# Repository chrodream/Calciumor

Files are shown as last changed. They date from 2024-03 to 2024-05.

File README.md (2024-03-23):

# Calciumor
## 特徴
- ESP32-S3をベースとした電卓\/無線マクロパッド
- Li-Poバッテリーによる充電に対応
- 128×64ドットのOLED表示 or 128×32ドット + 7セグ表示器

## スペック
| 項目 | Min. | Typ. | Max. | 
| :--- | ---- | ---- | ---- |
| USB入力電圧 [V] | 4.75 | 5.0 | 5.25 | 
| 消費電流 (電卓/バッテリー) [mA] | | | | 
| 消費電流(マクロパッド/バッテリー) [mA] | | | |
| 消費電流 (電卓/USB) [mA] | | | 750 |
| 消費電流(マクロパッド/USB) [mA] | | | 750 |
| 消費電流(スリープ) [mA] | | | | 
| バッテリー容量 [mAh] | 400 | - | - | 
| バッテリー電圧範囲 [V] | 2.9 | - | 4.2 |

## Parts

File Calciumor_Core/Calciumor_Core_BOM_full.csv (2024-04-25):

Reference | Value | Datasheet | Footprint | Qty | DNP | LCSC
C17 | 1000p | ~ | Capacitor_SMD:C_0402_1005Metric | 1 |  | C1523
C2,C12 | 0.01u | ~ | Capacitor_SMD:C_0402_1005Metric | 2 |  | C15195
C1,C3,C4,C6,C15,C18,C21 | 0.1u | ~ | Capacitor_SMD:C_0402_1005Metric | 7 |  | C307331
C10 | 1u | ~ | Capacitor_SMD:C_0402_1005Metric | 1 |  | C52923
C9,C11 | 4.7u | ~ | Capacitor_SMD:C_0603_1608Metric | 2 |  | C19666
C5,C7,C8 | 10u | ~ | Capacitor_SMD:C_0805_2012Metric | 3 |  | C440198
R27,R28 | 33 | ~ | Resistor_SMD:R_0603_1608Metric | 2 |  | C23140
R26 | 100 | ~ | Resistor_SMD:R_0603_1608Metric | 1 |  | C22775
R14 | 330 | ~ | Resistor_SMD:R_0402_1005Metric | 1 |  | C25104
R22,R33 | 470 | ~ | Resistor_SMD:R_0402_1005Metric | 2 |  | C25117
R11,R12,R13,R15 | 1k | ~ | Resistor_SMD:R_0402_1005Metric | 4 |  | C11702
R18 | 3.9k | ~ | Resistor_SMD:R_1206_3216Metric | 1 | DNP
R16,R17 | 5.1k | ~ | Resistor_SMD:R_0402_1005Metric | 2 |  | C25905
R8,R9,R10,R19,R23,R24,R25,R31 | 10k | ~ | Resistor_SMD:R_0402_1005Metric | 8 |  | C25744
R20 | 13k | ~ | Resistor_SMD:R_0603_1608Metric | 1 |  | C22797
R1 | 33k | ~ | Resistor_SMD:R_0603_1608Metric | 1 |  | C22967
R21 | 33k | ~ | Resistor_SMD:R_0402_1005Metric | 1 |  | C25779
R3,R4,R5,R29 | 100k | ~ | Resistor_SMD:R_0402_1005Metric | 4 |  | C25741
R2,R30 | 330k | ~ | Resistor_SMD:R_0603_1608Metric | 2 |  | C23137
R6 | 470k | ~ | Resistor_SMD:R_0603_1608Metric | 1 |  | C23178
R7 | 1M | ~ | Resistor_SMD:R_0603_1608Metric | 1 |  | C22935
U10 | AE-XC9306-5V |  | Calciumor:AE-XC9306-3V3 | 1 | DNP
U9 | AE-XC9306-3V3 |  | Calciumor:AE-XC9306-3V3 | 1 | DNP
D21 | B.Stat LED1 (White) | ~ | LED_SMD:LED_0603_1608Metric | 1 | DNP
D20 | B.Stat LED2 (White) | ~ | LED_SMD:LED_0603_1608Metric | 1 | DNP
D11 | B.Stat LED3 (White) | ~ | LED_SMD:LED_0603_1608Metric | 1 | DNP
D10 | B.Stat LED4 (White) | ~ | LED_SMD:LED_0603_1608Metric | 1 | DNP
U5 | BD5229G-1 |  | Package_TO_SOT_SMD:SOT-23-5 | 1 | DNP
J6 | Conn_01x05_Pin | ~ | Connector_JST:JST_PH_S4B-PH-SM4-TB_1x04-1MP_P2.00mm_Horizontal | 1 | DNP
J1 | Conn_01x07_Pin | ~ | Connector_JST:JST_PH_S6B-PH-SM4-TB_1x06-1MP_P2.00mm_Horizontal | 1 | DNP
D1,D2,D3,D4,D5,D6,D7,D8,D9,D12,D13,D14,D15,D16,D17,D18,D19 | D | ~ | Diode_SMD:D_SOD-123 | 17 |  | C81598
D23,D25 | DF3D18FU,LF | ~ | Package_TO_SOT_SMD:SOT-323_SC-70 | 2 | DNP
U3 | ESP32-S3-WROOM-1-N16R8 | https://www.espressif.com/sites/default/files/documentation/esp32-s3-wroom-1_wroom-1u_datasheet_en.pdf | RF_Module:ESP32-S3-WROOM-1 | 1 | DNP
D27 | LED Charging(Yellow) | ~ | LED_SMD:LED_0603_1608Metric | 1 | DNP
D24 | LED Power(White) | ~ | LED_SMD:LED_0603_1608Metric | 1 | DNP
J5 | Li-Po(PH_S2B_SMD) | ~ | Connector_JST:JST_PH_S2B-PH-SM4-TB_1x02-1MP_P2.00mm_Horizontal | 1
U1 | LM324APT |  | Package_SO:TSSOP-14_4.4x5mm_P0.65mm | 1 |  | C111180
U4 | MCP73831-2-OT | http://ww1.microchip.com/downloads/en/DeviceDoc/20001984g.pdf | Package_TO_SOT_SMD:SOT-23-5 | 1 | DNP
F1,F2 | MF-NSMF035X | ~ | Calciumor:MF-NSMF | 2 | DNP
H4,H7,H8,H10,H11 | MountingHole | ~ | MountingHole:MountingHole_2.2mm_M2 | 5 | DNP
U7 | NC7SV157 |  | Package_TO_SOT_SMD:SOT-363_SC-70-6 | 1 |  | C184123
J4 | NeoPixel | ~ | Connector_JST:JST_PH_S4B-PH-SM4-TB_1x04-1MP_P2.00mm_Horizontal | 1 | DNP
U2 | NJM12877F25 |  | Package_TO_SOT_SMD:SOT-23-5 | 1 | DNP
SW20 | Power_SW | ~ | Calciumor:THBP07 | 1 | DNP
SW4 | RotaryEncoder_Switch | ~ | Ultramarine-2:EC12 | 1 | DNP
D26,D28 | SS2040FL | ~ | Diode_SMD:D_SOD-123F | 2 | DNP
SW1,SW2,SW3,SW5,SW6,SW7,SW8,SW9,SW10,SW11,SW12,SW13,SW14,SW15,SW16,SW17,SW18 | SW_Push | ~ | Calciumor:MX_Choc_Socket | 17 | DNP
SW19 | TMHU27 |  | Calciumor:TMHU27 | 1 | DNP
SW21 | TVAF06 | ~ | Ultramarine-2:TVAF06 | 1
J2 | USB_C_Main | https://www.usb.org/sites/default/files/documents/usb_type-c.zip | Connector_USB:USB_C_Receptacle_G-Switch_GT-USB-7010ASV | 1 |  | C2988369
U8 | XC6194AA05ER-G |  | Calciumor:XC6194 | 1 |  | C18221112

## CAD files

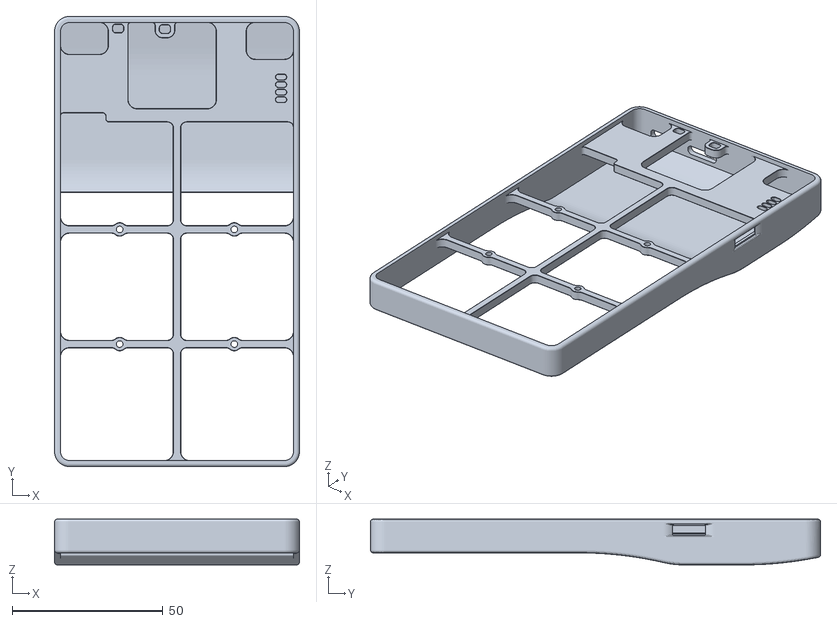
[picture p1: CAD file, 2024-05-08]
Calciumor_3DModel/Shell.stl
81.2 x 149.2 x 15.2

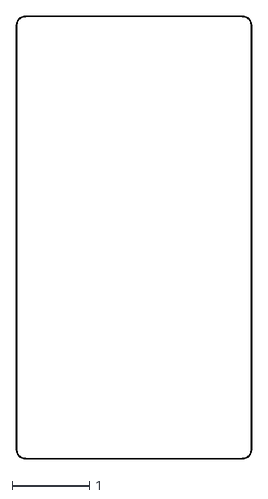
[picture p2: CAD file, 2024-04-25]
Calciumor_Core/Calciumor_Core-Edge_Cuts.dxf
3.04 x 5.71

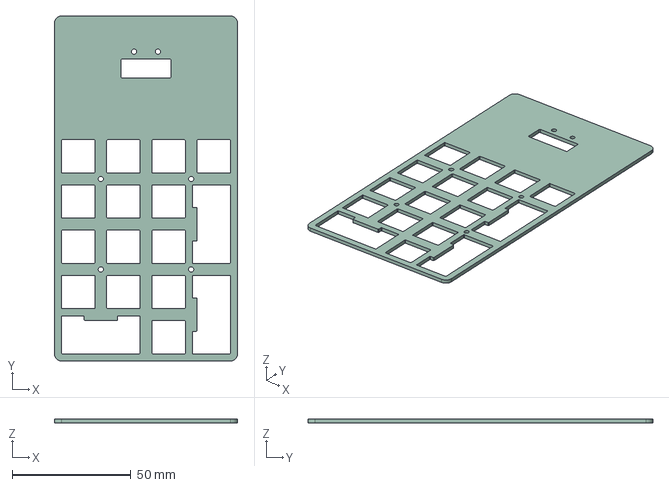
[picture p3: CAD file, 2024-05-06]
Calciumor_SwitchCover/Calciumor_SwitchCover.step
77.0 x 145.0 x 1.60 mm

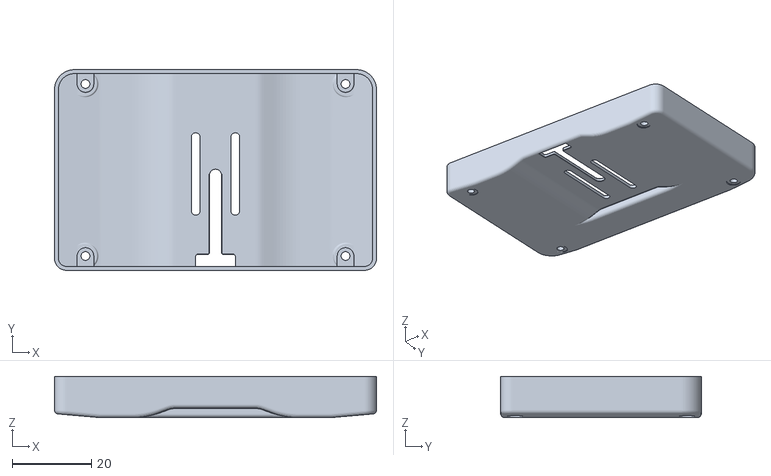
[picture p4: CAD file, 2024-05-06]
Calciumor_3DModel/OLED_Base.stl
81.2 x 50.6 x 10.4

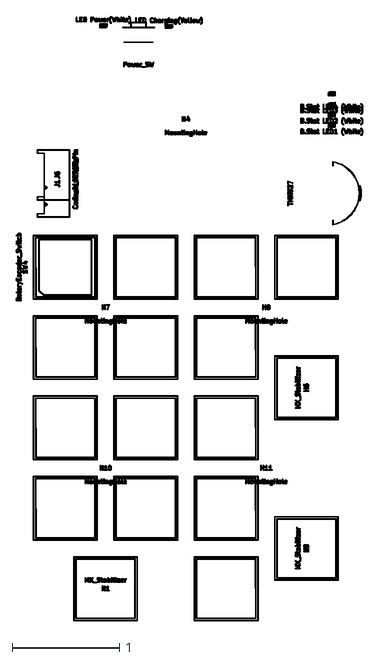
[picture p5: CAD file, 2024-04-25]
Calciumor_Core/Calciumor_Core-F_Fab.dxf
3.23 x 5.62

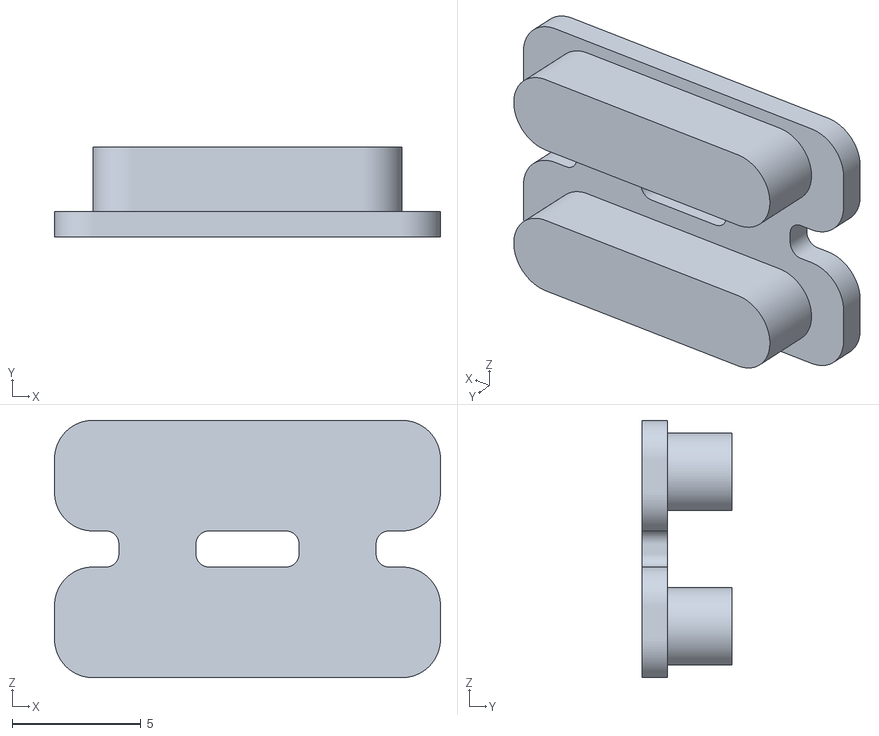
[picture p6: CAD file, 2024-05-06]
Calciumor_3DModel/Pow_SW.stl
15.0 x 3.50 x 10.00

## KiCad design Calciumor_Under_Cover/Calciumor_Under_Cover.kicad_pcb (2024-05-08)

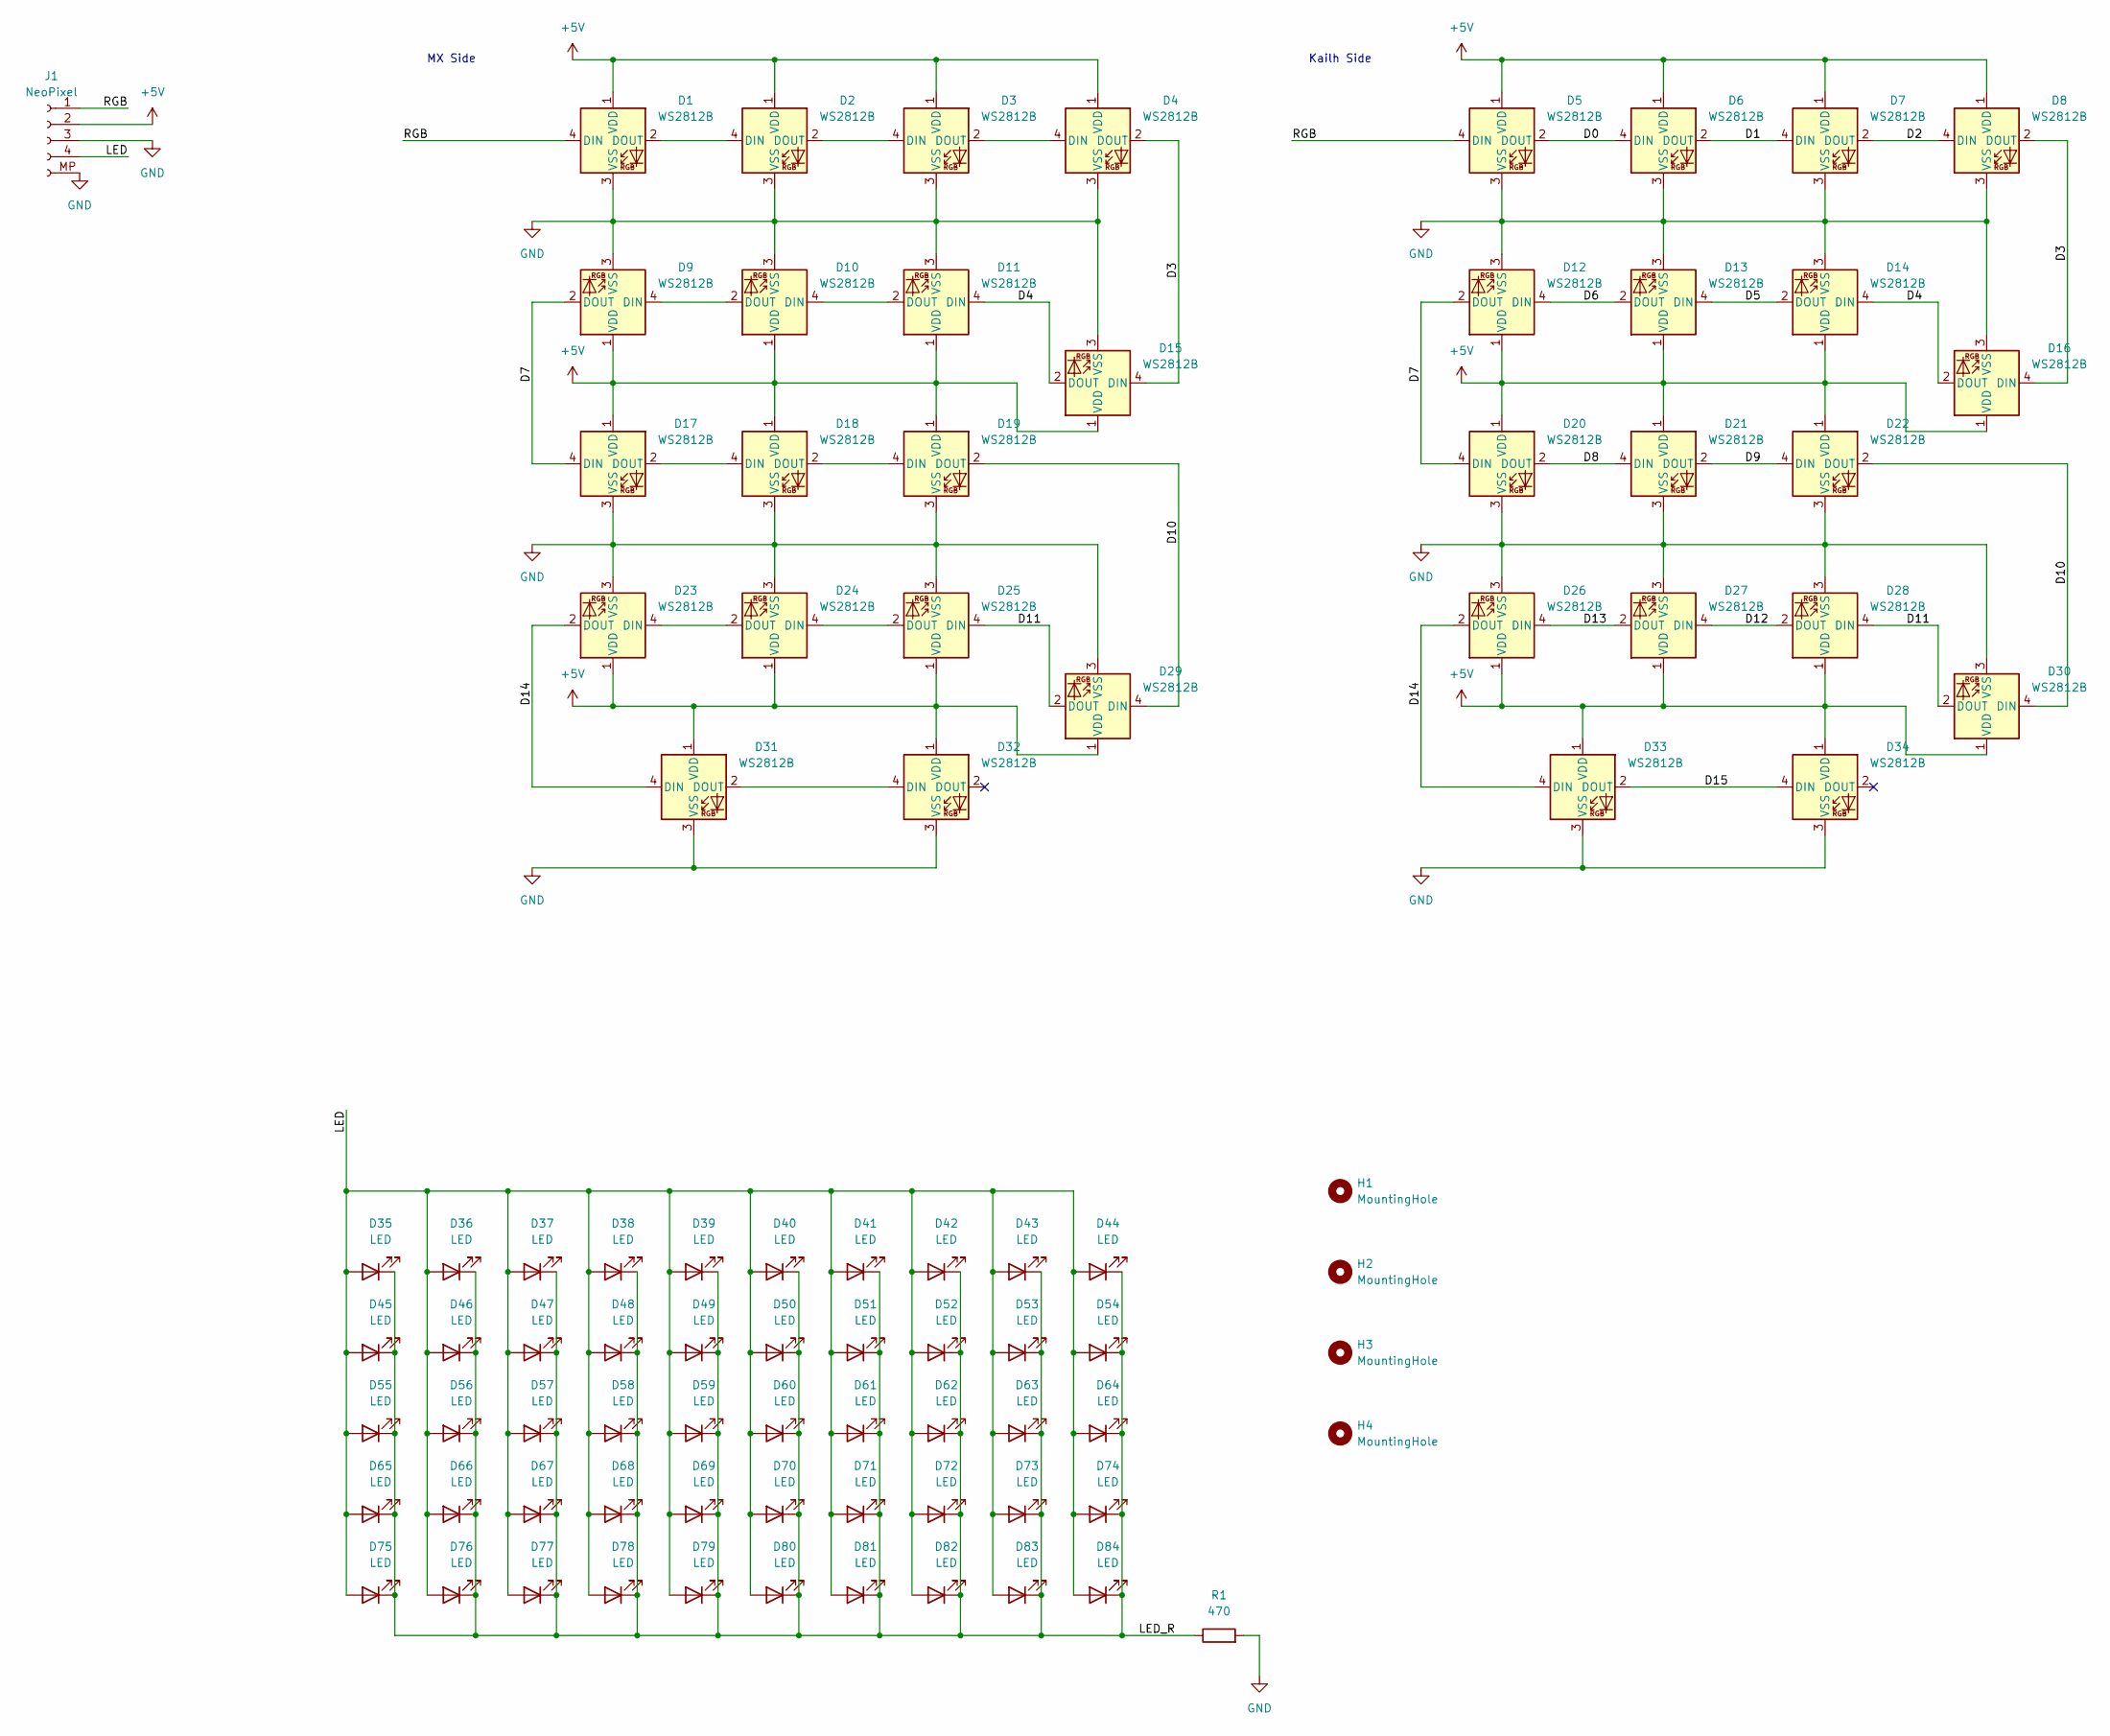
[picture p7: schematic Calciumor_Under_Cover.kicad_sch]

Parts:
D1, D2, D3, D4, D5, D6, D7, D8, D9, D10, D11, D12, D13, D14, D15, D16, D17, D18, D19, D20, D21, D22, D23, D24, D25, D26, D27, D28, D29, D30, D31, D32, D33, D34: WS2812B; LED_WS2812B_PLCC4_5.0x5.0mm_P3.2mm; LCSC C2843785
D35, D36, D37, D38, D39, D40, D41, D42, D43, D44, D45, D46, D47, D48, D49, D50, D51, D52, D53, D54, D55, D56, D57, D58, D59, D60, D61, D62, D63, D64, D65, D66, D67, D68, D69, D70, D71, D72, D73, D74, D75, D76, D77, D78, D79, D80, D81, D82, D83, D84: LED; LED_0603_1608Metric; LCSC C2290
H1, H2, H3, H4: MountingHole; MountingHole_2.2mm_M2
J1: NeoPixel; JST_PH_S4B-PH-SM4-TB_1x04-1MP_P2.00mm_Horizontal
R1: 470; R_1206_3216Metric

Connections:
+5V: D1.1 (VDD), D2.1 (VDD), D3.1 (VDD), D4.1 (VDD), D5.1 (VDD), D6.1 (VDD), D7.1 (VDD), D8.1 (VDD), D9.1 (VDD), D10.1 (VDD), D11.1 (VDD), D12.1 (VDD), D13.1 (VDD), D14.1 (VDD), D15.1 (VDD), D16.1 (VDD), D17.1 (VDD), D18.1 (VDD), D19.1 (VDD), D20.1 (VDD), D21.1 (VDD), D22.1 (VDD), D23.1 (VDD), D24.1 (VDD), D25.1 (VDD), D26.1 (VDD), D27.1 (VDD), D28.1 (VDD), D29.1 (VDD), D30.1 (VDD), D31.1 (VDD), D32.1 (VDD), D33.1 (VDD), D34.1 (VDD), J1.2
/D0: D5.2 (DOUT), D6.4 (DIN)
/D1: D6.2 (DOUT), D7.4 (DIN)
/D2: D7.2 (DOUT), D8.4 (DIN)
/D3: D4.2 (DOUT), D8.2 (DOUT), D15.4 (DIN), D16.4 (DIN)
/D4: D11.4 (DIN), D14.4 (DIN), D15.2 (DOUT), D16.2 (DOUT)
/D5: D13.4 (DIN), D14.2 (DOUT)
/D6: D12.4 (DIN), D13.2 (DOUT)
/D7: D9.2 (DOUT), D12.2 (DOUT), D17.4 (DIN), D20.4 (DIN)
/D8: D20.2 (DOUT), D21.4 (DIN)
/D9: D21.2 (DOUT), D22.4 (DIN)
/D10: D19.2 (DOUT), D22.2 (DOUT), D29.4 (DIN), D30.4 (DIN)
/D11: D25.4 (DIN), D28.4 (DIN), D29.2 (DOUT), D30.2 (DOUT)
/D12: D27.4 (DIN), D28.2 (DOUT)
/D13: D26.4 (DIN), D27.2 (DOUT)
/D14: D23.2 (DOUT), D26.2 (DOUT), D31.4 (DIN), D33.4 (DIN)
/D15: D33.2 (DOUT), D34.4 (DIN)
/LED: D35.2 (A), D36.2 (A), D37.2 (A), D38.2 (A), D39.2 (A), D40.2 (A), D41.2 (A), D42.2 (A), D43.2 (A), D44.2 (A), D45.2 (A), D46.2 (A), D47.2 (A), D48.2 (A), D49.2 (A), D50.2 (A), D51.2 (A), D52.2 (A), D53.2 (A), D54.2 (A), D55.2 (A), D56.2 (A), D57.2 (A), D58.2 (A), D59.2 (A), D60.2 (A), D61.2 (A), D62.2 (A), D63.2 (A), D64.2 (A), D65.2 (A), D66.2 (A), D67.2 (A), D68.2 (A), D69.2 (A), D70.2 (A), D71.2 (A), D72.2 (A), D73.2 (A), D74.2 (A), D75.2 (A), D76.2 (A), D77.2 (A), D78.2 (A), D79.2 (A), D80.2 (A), D81.2 (A), D82.2 (A), D83.2 (A), D84.2 (A), J1.4
/LED_R: D35.1 (K), D36.1 (K), D37.1 (K), D38.1 (K), D39.1 (K), D40.1 (K), D41.1 (K), D42.1 (K), D43.1 (K), D44.1 (K), D45.1 (K), D46.1 (K), D47.1 (K), D48.1 (K), D49.1 (K), D50.1 (K), D51.1 (K), D52.1 (K), D53.1 (K), D54.1 (K), D55.1 (K), D56.1 (K), D57.1 (K), D58.1 (K), D59.1 (K), D60.1 (K), D61.1 (K), D62.1 (K), D63.1 (K), D64.1 (K), D65.1 (K), D66.1 (K), D67.1 (K), D68.1 (K), D69.1 (K), D70.1 (K), D71.1 (K), D72.1 (K), D73.1 (K), D74.1 (K), D75.1 (K), D76.1 (K), D77.1 (K), D78.1 (K), D79.1 (K), D80.1 (K), D81.1 (K), D82.1 (K), D83.1 (K), D84.1 (K), R1.1
/RGB: D1.4 (DIN), D5.4 (DIN), J1.1
GND: D1.3 (VSS), D2.3 (VSS), D3.3 (VSS), D4.3 (VSS), D5.3 (VSS), D6.3 (VSS), D7.3 (VSS), D8.3 (VSS), D9.3 (VSS), D10.3 (VSS), D11.3 (VSS), D12.3 (VSS), D13.3 (VSS), D14.3 (VSS), D15.3 (VSS), D16.3 (VSS), D17.3 (VSS), D18.3 (VSS), D19.3 (VSS), D20.3 (VSS), D21.3 (VSS), D22.3 (VSS), D23.3 (VSS), D24.3 (VSS), D25.3 (VSS), D26.3 (VSS), D27.3 (VSS), D28.3 (VSS), D29.3 (VSS), D30.3 (VSS), D31.3 (VSS), D32.3 (VSS), D33.3 (VSS), D34.3 (VSS), J1.3, J1.MP (Pin_5), R1.2
unnamed: D1.2 (DOUT), D2.4 (DIN)
unnamed: D2.2 (DOUT), D3.4 (DIN)
unnamed: D3.2 (DOUT), D4.4 (DIN)
unnamed: D10.4 (DIN), D11.2 (DOUT)
unnamed: D9.4 (DIN), D10.2 (DOUT)
unnamed: D17.2 (DOUT), D18.4 (DIN)
unnamed: D18.2 (DOUT), D19.4 (DIN)
unnamed: D23.4 (DIN), D24.2 (DOUT)
unnamed: D24.4 (DIN), D25.2 (DOUT)
unnamed: D31.2 (DOUT), D32.4 (DIN)

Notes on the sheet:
Kailh Side
MX Side

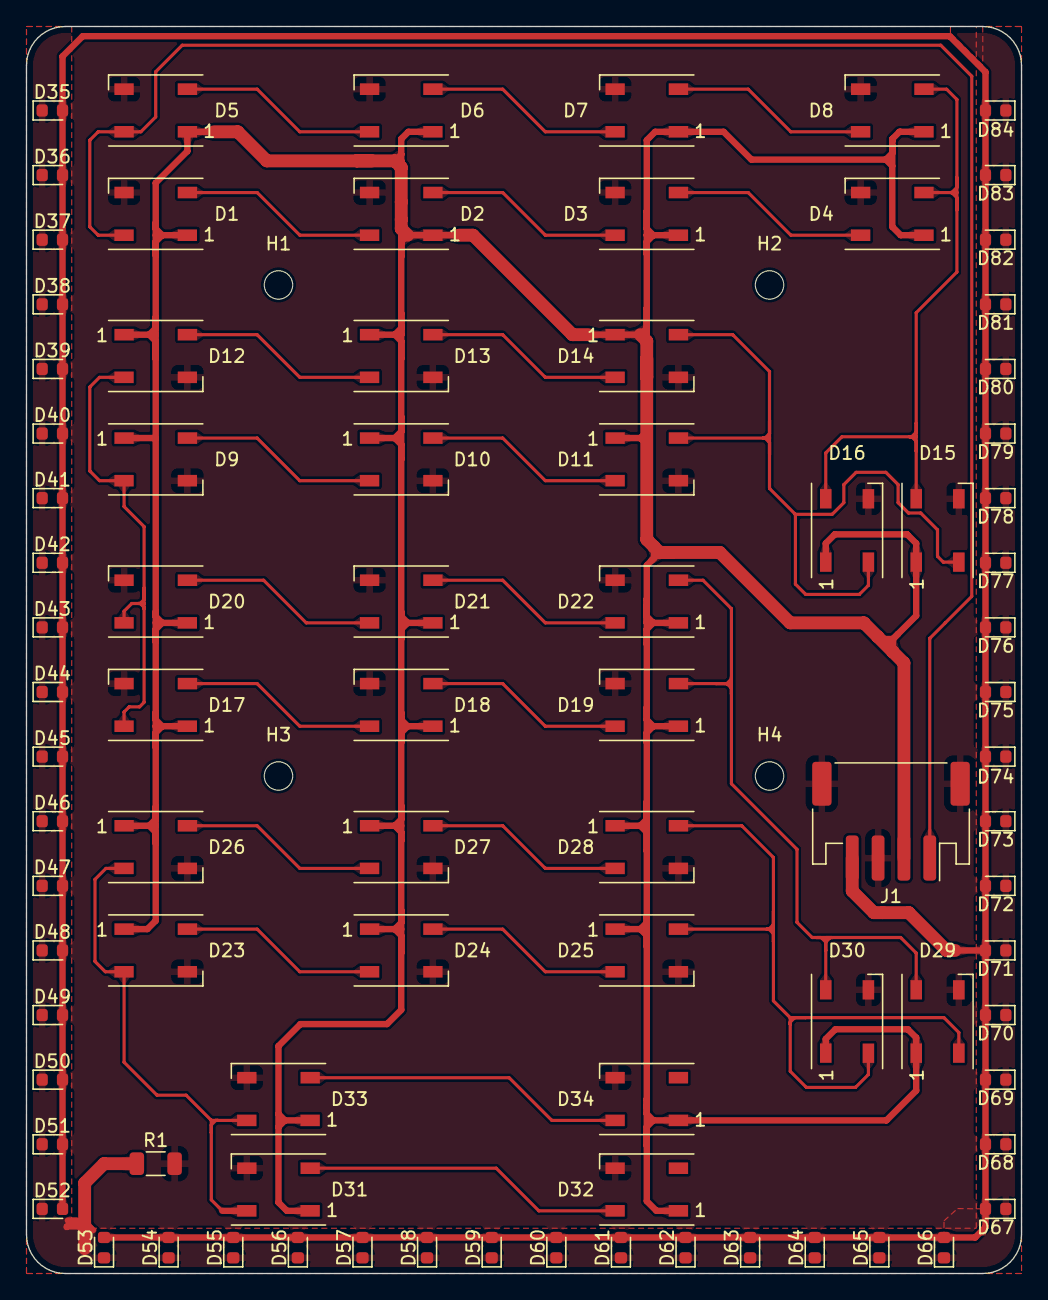
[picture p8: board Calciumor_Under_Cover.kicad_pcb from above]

Board: 2 copper layers, 77.0 x 96.5 mm, 90 parts (0 on the bottom side), 31 nets.

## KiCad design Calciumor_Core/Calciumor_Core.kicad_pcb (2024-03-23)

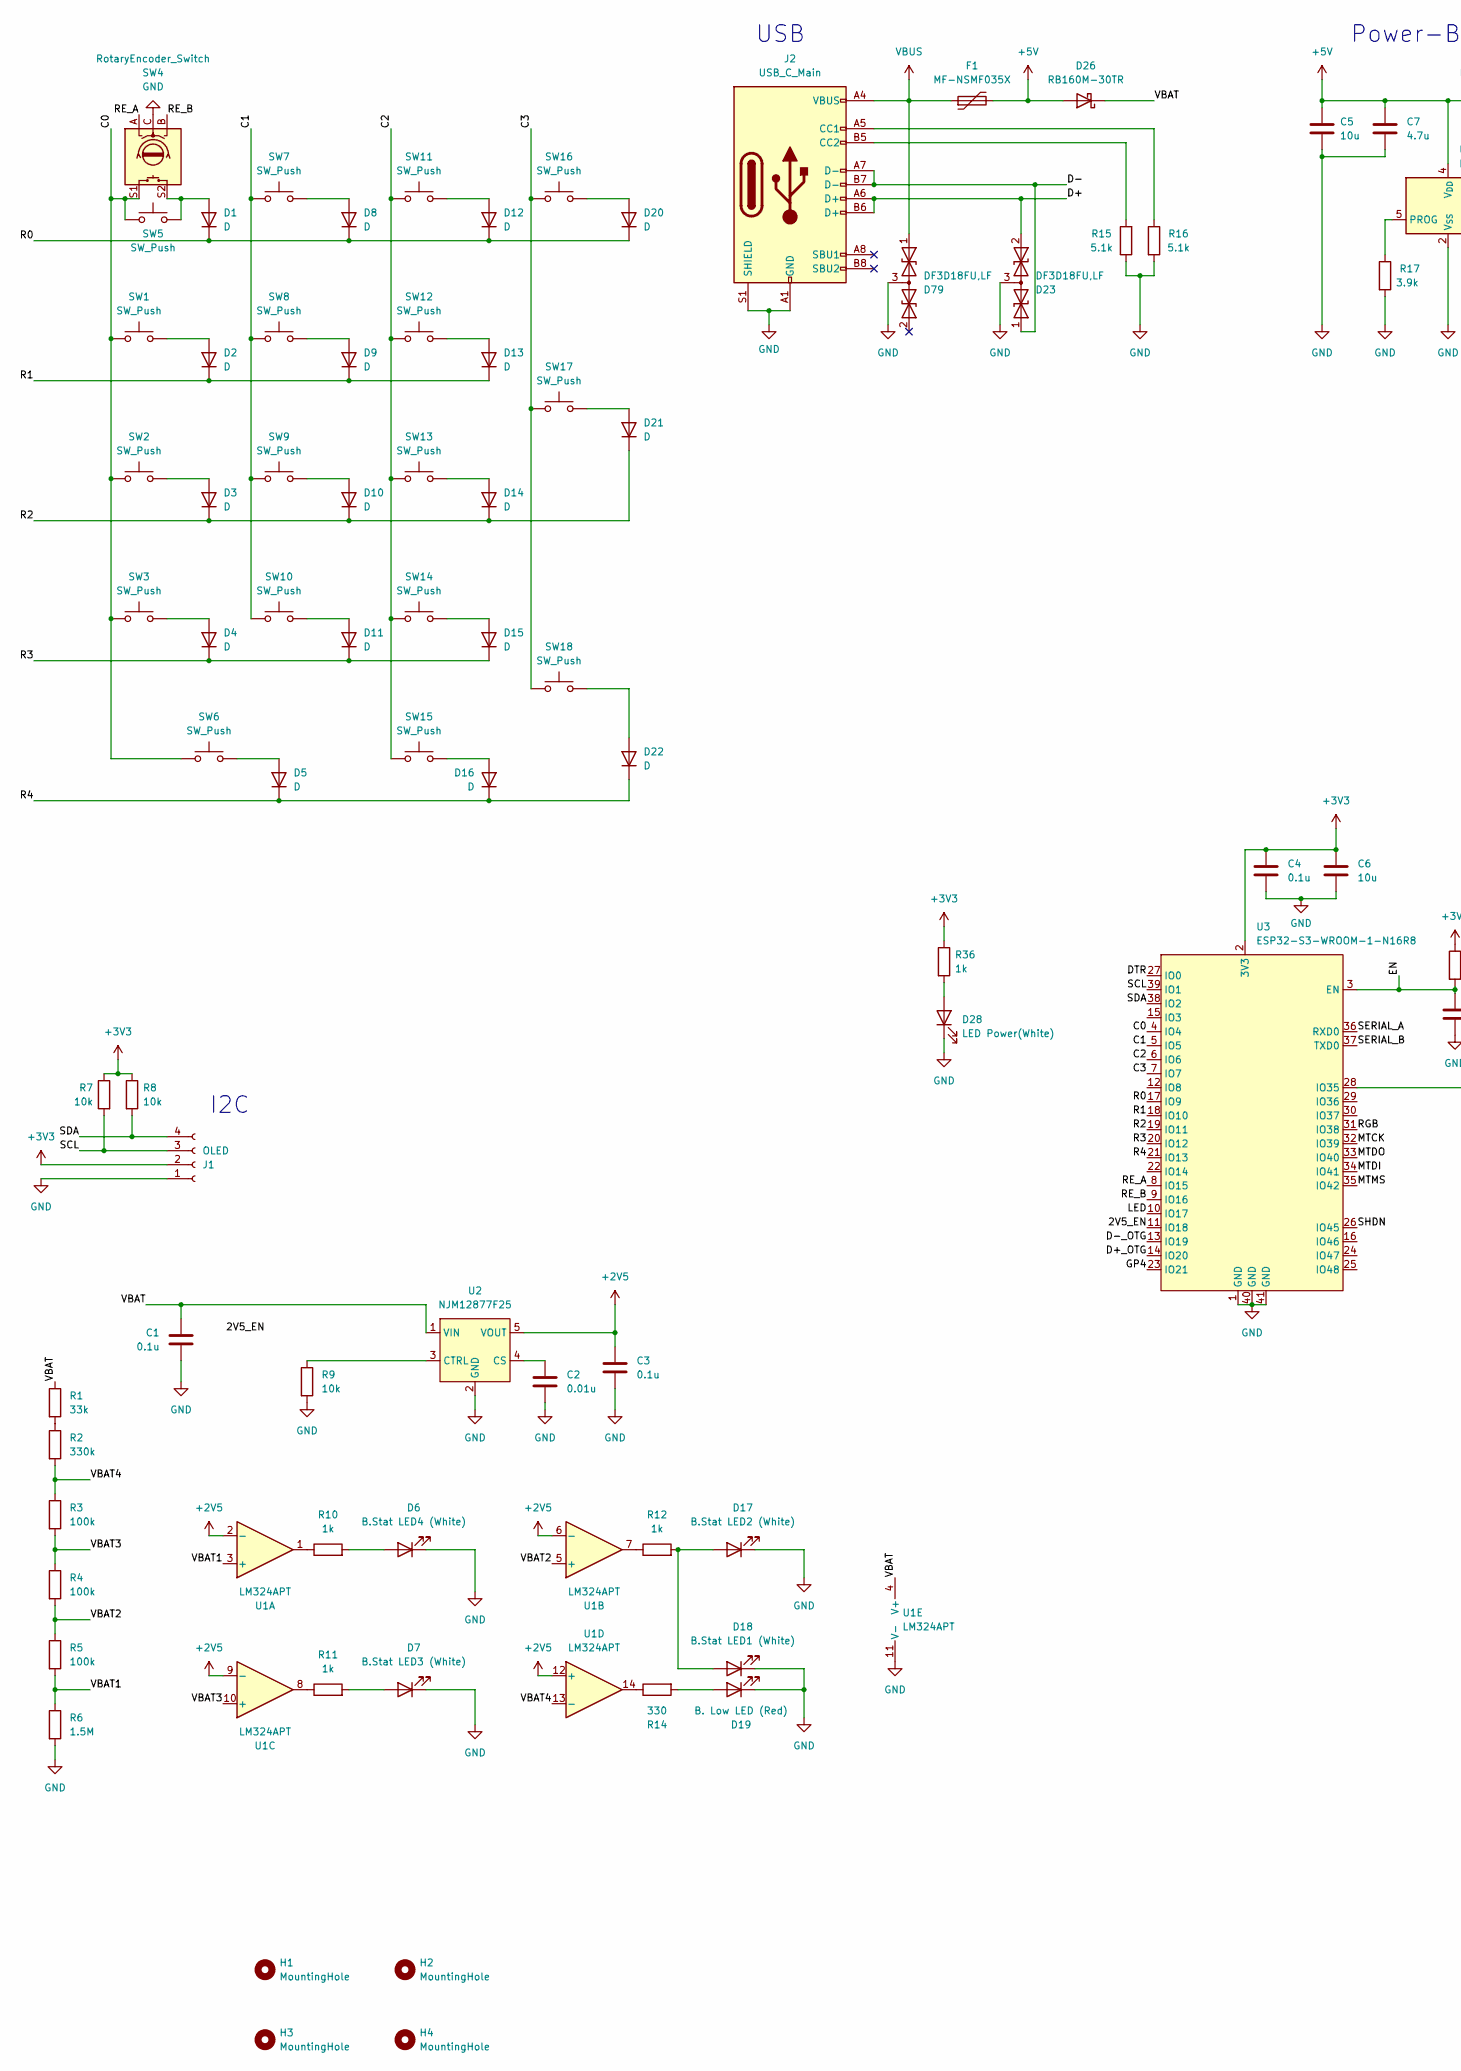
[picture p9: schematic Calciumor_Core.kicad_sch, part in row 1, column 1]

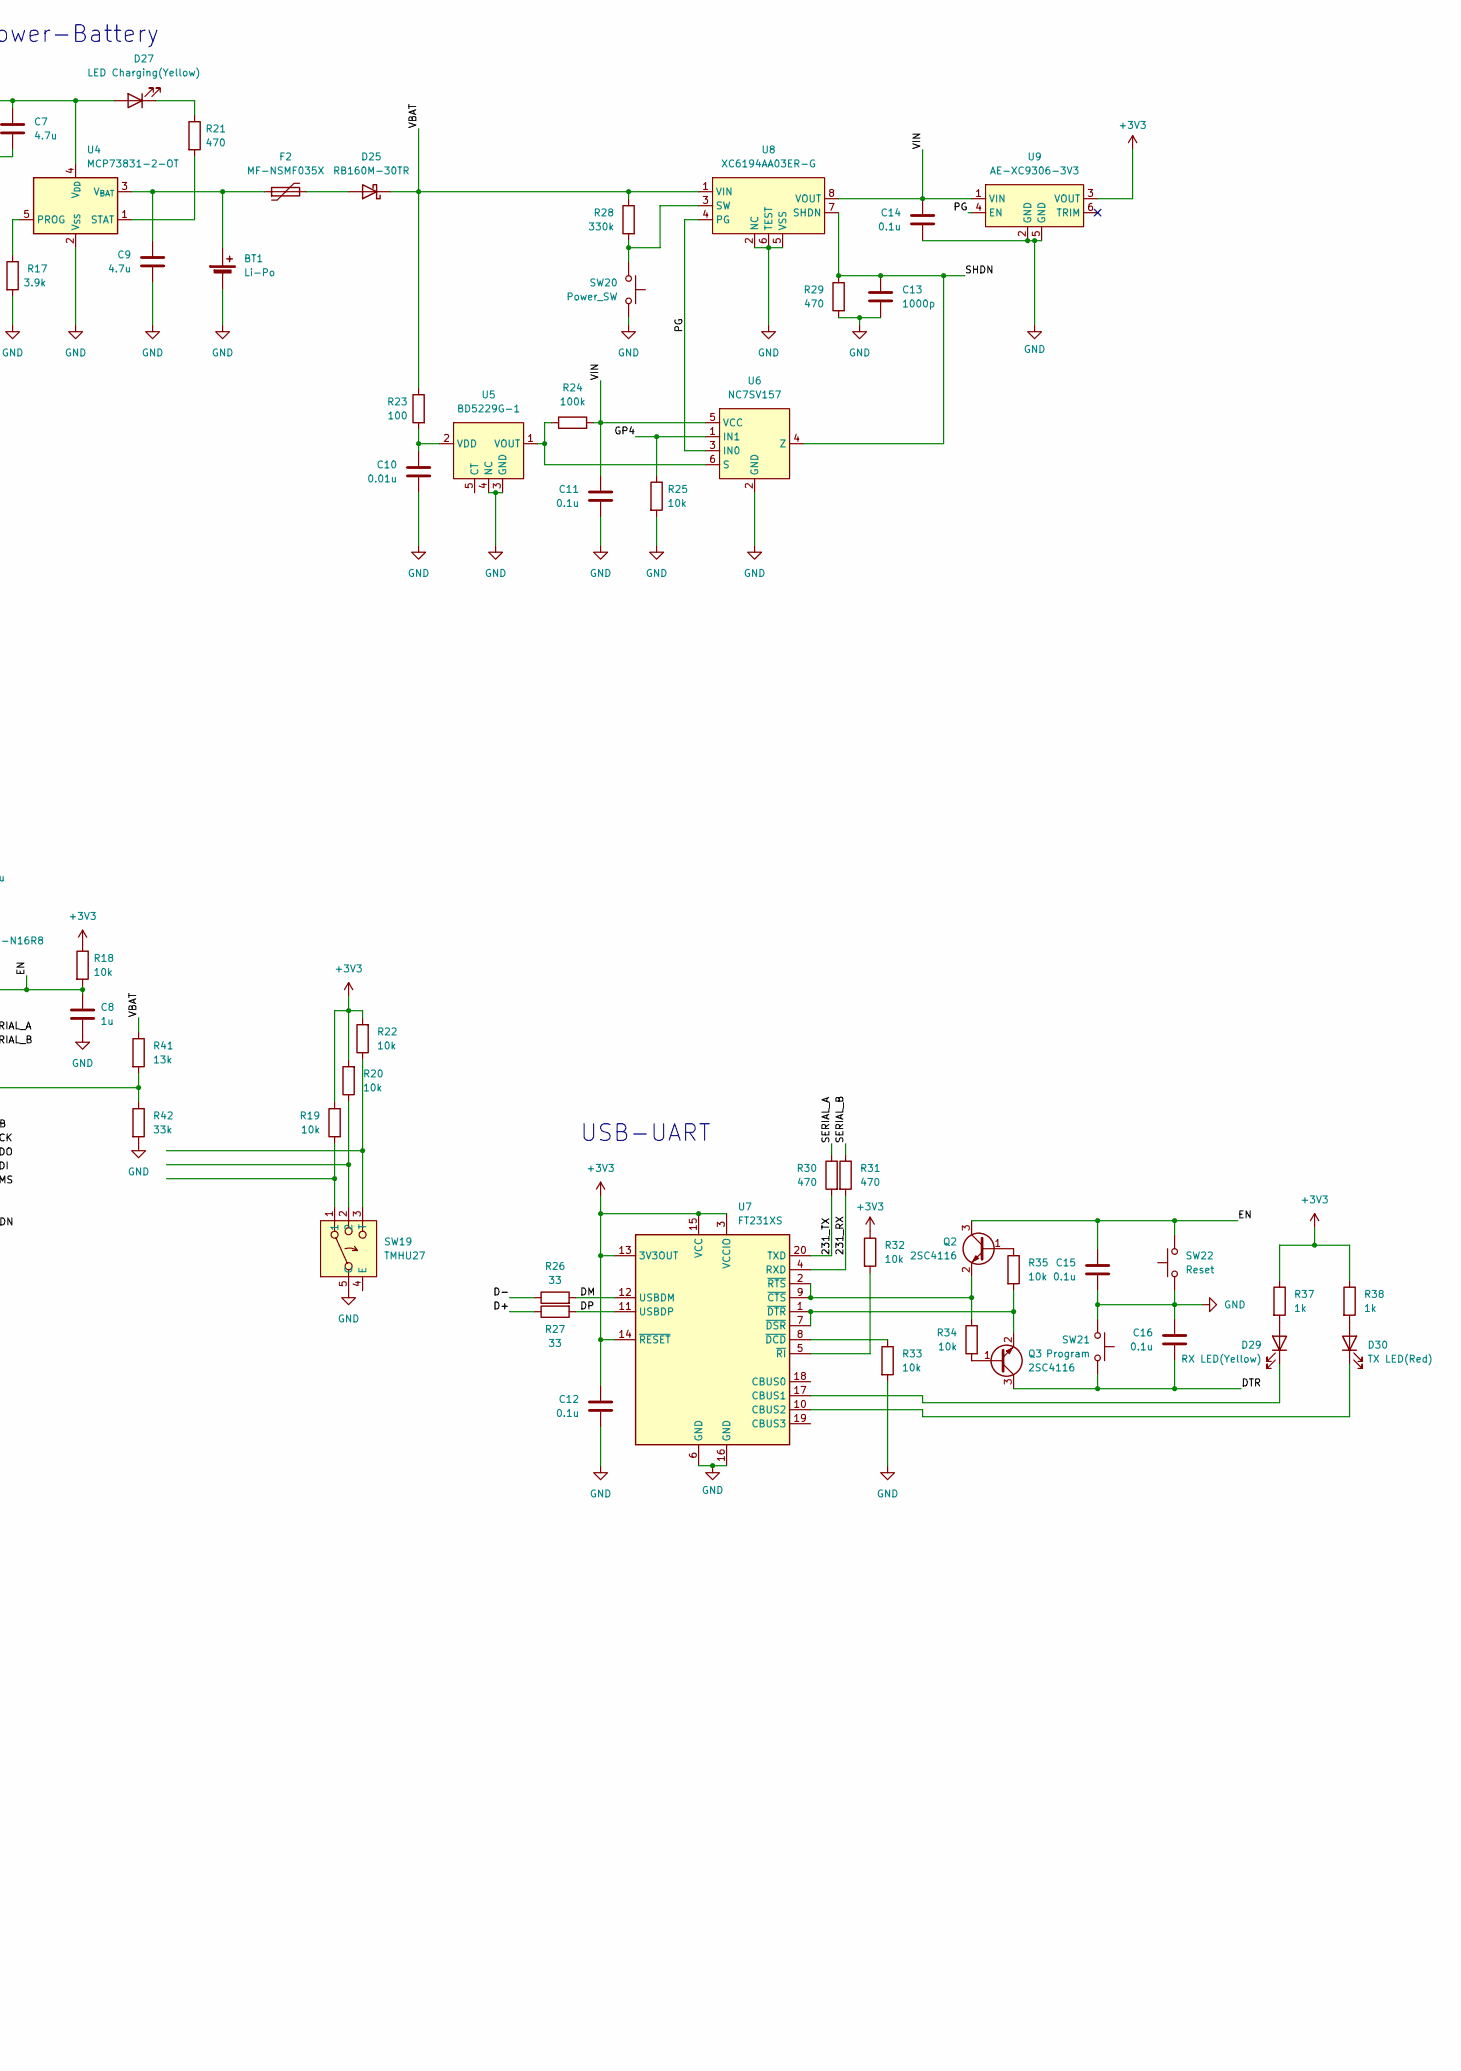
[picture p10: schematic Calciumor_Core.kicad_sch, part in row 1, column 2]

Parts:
BT1: Li-Po; JST_PH_S2B-PH-K_1x02_P2.00mm_Horizontal
C1, C3, C4, C11, C12, C14, C15, C16: 0.1u; C_0402_1005Metric; LCSC C307331
C2, C10: 0.01u; C_0402_1005Metric; LCSC C15195
C5, C6: 10u; C_0805_2012Metric; LCSC C15850
C7, C9: 4.7u; C_0603_1608Metric; LCSC C19666
C8: 1u; C_0402_1005Metric; LCSC C52923
C13: 1000p; C_0402_1005Metric; LCSC C307331
D1, D2, D3, D4, D5, D8, D9, D10, D11, D12, D13, D14, D15, D16, D20, D21, D22: D; SOD-123; LCSC C81598
D6: B.Stat LED4 (White); LED_0603_1608Metric; LCSC C2290
D7: B.Stat LED3 (White); LED_0603_1608Metric; LCSC C2290
D17: B.Stat LED2 (White); LED_0603_1608Metric; LCSC C2290
D18: B.Stat LED1 (White); LED_0603_1608Metric; LCSC C2290
D19: B. Low LED (Red); LED_0603_1608Metric; LCSC C2286
D23, D79: DF3D18FU,LF; SOT-323_SC-70
D25, D26: RB160M-30TR; D_SOD-123F
D27: LED Charging(Yellow); LED_0603_1608Metric; LCSC C72038
D28: LED Power(White); LED_0603_1608Metric; LCSC C2290
D29: RX LED(Yellow); LED_0603_1608Metric; LCSC C72038
D30: TX LED(Red); LED_0603_1608Metric; LCSC C2286
F1, F2: MF-NSMF035X; MF-NSMF
H1, H2, H3, H4: MountingHole; MountingHole_2.2mm_M2
J1: OLED; PinHeader_1x04_P2.54mm_Horizontal
J2: USB_C_Main; USB_C_Receptacle_G-Switch_GT-USB-7010ASV; LCSC C2988369
Q2, Q3: 2SC4116; SOT-323_SC-70
R1: 33k; R_0603_1608Metric; LCSC C22967
R2: 330k; R_0603_1608Metric; LCSC C22807
R3, R4, R5: 100k; R_0402_1005Metric; LCSC C25779
R6: 1.5M; R_0603_1608Metric; LCSC C23178
R7, R8, R9, R18, R19, R20, R22, R25, R32, R33, R34, R35: 10k; R_0402_1005Metric; LCSC C25744
R10, R11, R12, R36, R37, R38: 1k; R_0402_1005Metric; LCSC C11702
R14: 330; R_0402_1005Metric; LCSC C11702
R15, R16: 5.1k; R_0402_1005Metric; LCSC C25905
R17: 3.9k; R_1206_3216Metric
R21, R29, R30, R31: 470; R_0402_1005Metric; LCSC C25117
R23: 100; R_0603_1608Metric; LCSC C22775
R24: 100k; R_0402_1005Metric; LCSC C25741
R26, R27: 33; R_0603_1608Metric; LCSC C23140
R28: 330k; R_0402_1005Metric; LCSC C23137
R41: 13k; R_0603_1608Metric; LCSC C22797
R42: 33k; R_0402_1005Metric; LCSC C22967
SW1, SW2, SW3, SW5, SW6, SW7, SW8, SW9, SW10, SW11, SW12, SW13, SW14, SW15, SW16, SW17, SW18: SW_Push; MX_Choc_Socket
SW4: RotaryEncoder_Switch; EC12
SW19: TMHU27
SW20: Power_SW; THBP07
SW21: Program; TVAF06
SW22: Reset; TVAF06
U1: LM324APT; TSSOP-14_4.4x5mm_P0.65mm; LCSC C111180
U2: NJM12877F25; SOT-23-5
U3: ESP32-S3-WROOM-1-N16R8; ESP32-S3-WROOM-1
U4: MCP73831-2-OT; SOT-23-5
U5: BD5229G-1; SOT-23-5
U6: NC7SV157; SOT-363_SC-70-6
U7: FT231XS; SSOP-20_3.9x8.7mm_P0.635mm; LCSC C89607
U8: XC6194AA03ER-G; XC6194; LCSC C18221112
U9: AE-XC9306-3V3

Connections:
+2V5: C3.1, U1.2 (-), U1.6 (-), U1.9 (-), U1.12 (+), U2.5 (VOUT)
+3V3: C4.1, C6.1, C12.1, J1.2, R7.1, R8.1, R18.1, R19.1, R20.2, R22.2, R32.1, R36.1, R37.1, R38.1, U3.2 (3V3), U7.3 (VCCIO), U7.13 (3V3OUT), U7.14 (~RESET), U7.15 (VCC), U9.3 (VOUT)
+5V: C5.1, C7.1, D26.2 (A), D27.2 (A), F1.2, U4.4 (V_{DD})
/2V5_EN: U3.11 (IO18)
/231_RX: R31.2, U7.4 (RXD)
/231_TX: R30.2, U7.20 (TXD)
/C0: SW1.1, SW2.1, SW3.1, SW4.S1, SW5.1, SW6.1, U3.4 (IO4)
/C1: SW7.1, SW8.1, SW9.1, SW10.1, U3.5 (IO5)
/C2: SW11.1, SW12.1, SW13.1, SW14.1, SW15.1, U3.6 (IO6)
/C3: SW16.1, SW17.2, SW18.2, U3.7 (IO7)
/D+: D23.2 (A2), J2.A6 (D+), J2.B6 (D+), R27.1
/D+_OTG: U3.14 (IO20)
/D-: D23.1 (A1), J2.A7 (D-), J2.B7 (D-), R26.1
/D-_OTG: U3.13 (IO19)
/DM: R26.2, U7.12 (USBDM)
/DP: R27.2, U7.11 (USBDP)
/DTR: C16.2, Q3.3 (C), SW21.1, U3.27 (IO0)
/EN: C8.1, C15.1, Q2.3 (C), R18.2, SW22.2, U3.3 (EN)
/GP4: R25.1, U3.23 (IO21), U6.1 (IN1)
/LED: U3.10 (IO17)
/MTCK: U3.32 (IO39)
/MTDI: U3.34 (IO41)
/MTDO: U3.33 (IO40)
/MTMS: U3.35 (IO42)
/PG: U6.3 (IN0), U8.4 (PG), U9.4 (EN)
/R0: D1.1 (K), D8.1 (K), D12.1 (K), D20.1 (K), U3.17 (IO9)
/R1: D2.1 (K), D9.1 (K), D13.1 (K), U3.18 (IO10)
/R2: D3.1 (K), D10.1 (K), D14.1 (K), D21.1 (K), U3.19 (IO11)
/R3: D4.1 (K), D11.1 (K), D15.1 (K), U3.20 (IO12)
/R4: D5.1 (K), D16.1 (K), D22.1 (K), U3.21 (IO13)
/RE_A: SW4.A, U3.8 (IO15)
/RE_B: SW4.B, U3.9 (IO16)
/RGB: U3.31 (IO38)
/SCL: J1.3, R7.2, U3.39 (IO1)
/SDA: J1.4, R8.2, U3.38 (IO2)
/SERIAL_A: R30.1, U3.36 (RXD0)
/SERIAL_B: R31.1, U3.37 (TXD0)
/SHDN: C13.1, R29.1, U3.26 (IO45), U6.4 (Z), U8.7 (SHDN)
/VBAT: C1.1, D25.1 (K), D26.1 (K), R1.1, R23.1, R28.1, R41.1, U1.4 (V+), U2.1 (VIN), U8.1 (VIN)
/VBAT1: R5.2, R6.1, U1.3 (+)
/VBAT2: R4.2, R5.1, U1.5 (+)
/VBAT3: R3.2, R4.1, U1.10 (+)
/VBAT4: R2.2, R3.1, U1.13 (-)
/VIN: C11.1, C14.1, R24.2, U6.5 (VCC), U8.8 (VOUT), U9.1 (VIN)
GND: BT1.2 (-), C1.2, C2.2, C3.2, C4.2, C5.2, C6.2, C7.2, C8.2, C9.2, C10.2, C11.2, C12.2, C13.2, C14.2, C15.2, C16.1, D6.1 (K), D7.1 (K), D17.1 (K), D18.1 (K), D19.1 (K), D23.3 (common), D28.1 (K), D79.3 (common), J1.1, J2.A1 (GND), J2.A12 (GND), J2.B1 (GND), J2.B12 (GND), J2.S1 (SHIELD), R6.2, R9.2, R15.1, R16.2, R17.2, R25.2, R29.2, R33.2, R42.2, SW4.C, SW19.5 (C), SW20.1, SW21.2, SW22.1, U1.11 (V-), U2.2 (GND), U3.1 (GND), U3.40 (GND), U3.41 (GND), U4.2 (V_{SS}), U5.3 (GND), U5.4 (NC), U6.2 (GND), U7.6 (GND), U7.16 (GND), U8.2 (NC), U8.5 (VSS), U8.6 (TEST), U9.2 (GND), U9.5 (GND)
unnamed: BT1.1 (+), C9.1, F2.1, U4.3 (V_{BAT})
unnamed: D1.2 (A), SW4.S2, SW5.2
unnamed: D2.2 (A), SW1.2
unnamed: D3.2 (A), SW2.2
unnamed: D4.2 (A), SW3.2
unnamed: D5.2 (A), SW6.2
unnamed: D6.2 (A), R10.2
unnamed: D7.2 (A), R11.2
unnamed: D8.2 (A), SW7.2
unnamed: D9.2 (A), SW8.2
unnamed: D10.2 (A), SW9.2
unnamed: D11.2 (A), SW10.2
unnamed: D12.2 (A), SW11.2
unnamed: D13.2 (A), SW12.2
unnamed: D14.2 (A), SW13.2
unnamed: D15.2 (A), SW14.2
unnamed: D16.2 (A), SW15.2
unnamed: D17.2 (A), D18.2 (A), R12.2
unnamed: D19.2 (A), R14.2
unnamed: D20.2 (A), SW16.2
unnamed: D21.2 (A), SW17.1
unnamed: D22.2 (A), SW18.1
unnamed: D25.2 (A), F2.2
unnamed: D27.1 (K), R21.1
unnamed: D28.2 (A), R36.2
unnamed: D29.2 (A), R37.2
unnamed: D29.1 (K), U7.17 (CBUS1)
unnamed: D30.2 (A), R38.2
unnamed: D30.1 (K), U7.10 (CBUS2)
unnamed: J2.A5 (CC1), R16.1
unnamed: J2.B5 (CC2), R15.2
unnamed: Q2.1 (B), R35.1
unnamed: Q2.2 (E), R34.1, U7.2 (~RTS), U7.9 (~CTS)
unnamed: Q3.1 (B), R34.2
unnamed: Q3.2 (E), R35.2, U7.1 (~DTR), U7.7 (~DSR)
unnamed: R1.2, R2.1
unnamed: R10.1, U1.1
unnamed: R11.1, U1.8
unnamed: R12.1, U1.7
unnamed: R14.1, U1.14
unnamed: R19.2, SW19.1
unnamed: R20.1, SW19.2
unnamed: R22.1, SW19.3 (T)
unnamed: C2.1, U2.4 (CS)
unnamed: R9.1, U2.3 (CTRL)
unnamed: R41.2, R42.1, U3.28 (IO35)
unnamed: R17.1, U4.5 (PROG)
unnamed: R21.2, U4.1 (STAT)
unnamed: C10.1, R23.2, U5.2 (VDD)
unnamed: R24.1, U5.1 (VOUT), U6.6 (S)
unnamed: R33.1, U7.8 (~DCD)
unnamed: R32.2, U7.5 (~RI)
unnamed: R28.2, SW20.2, U8.3 (SW)
VBUS: D79.1 (A1), F1.1, J2.A4 (VBUS), J2.A9 (VBUS), J2.B4 (VBUS), J2.B9 (VBUS)

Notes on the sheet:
USB
I2C
Power-Battery
USB-UART

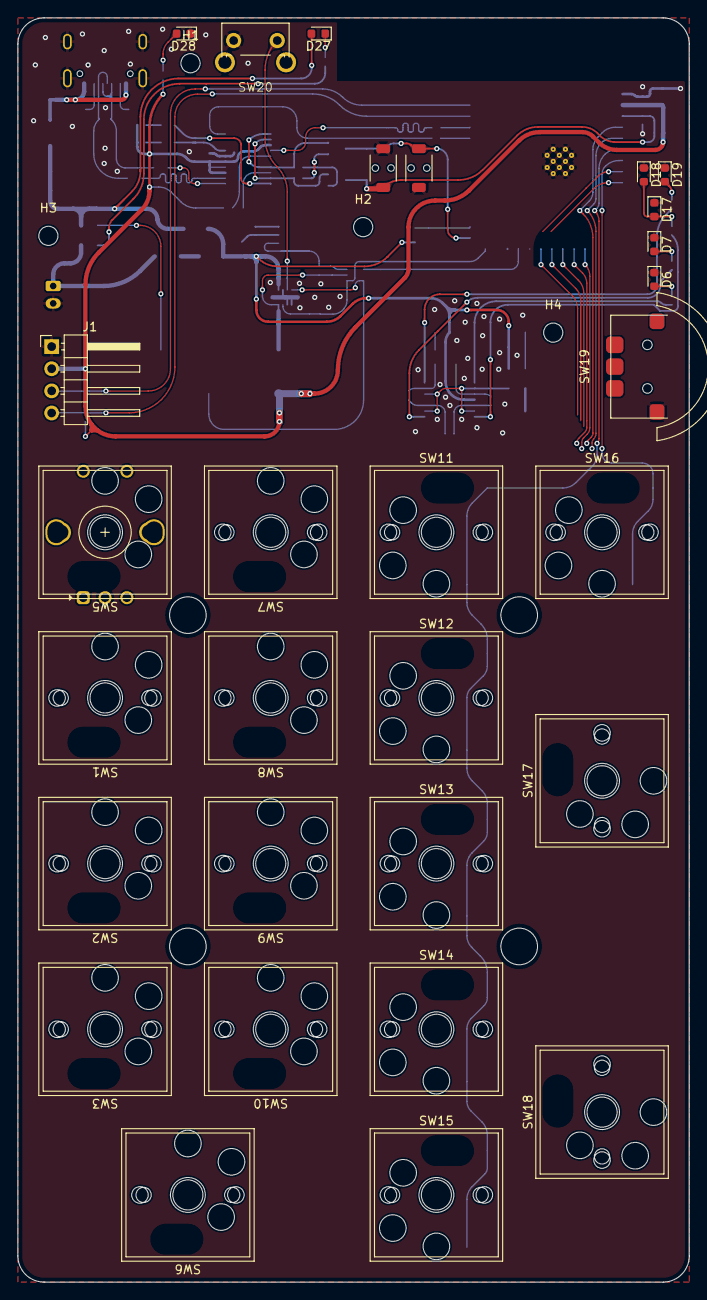
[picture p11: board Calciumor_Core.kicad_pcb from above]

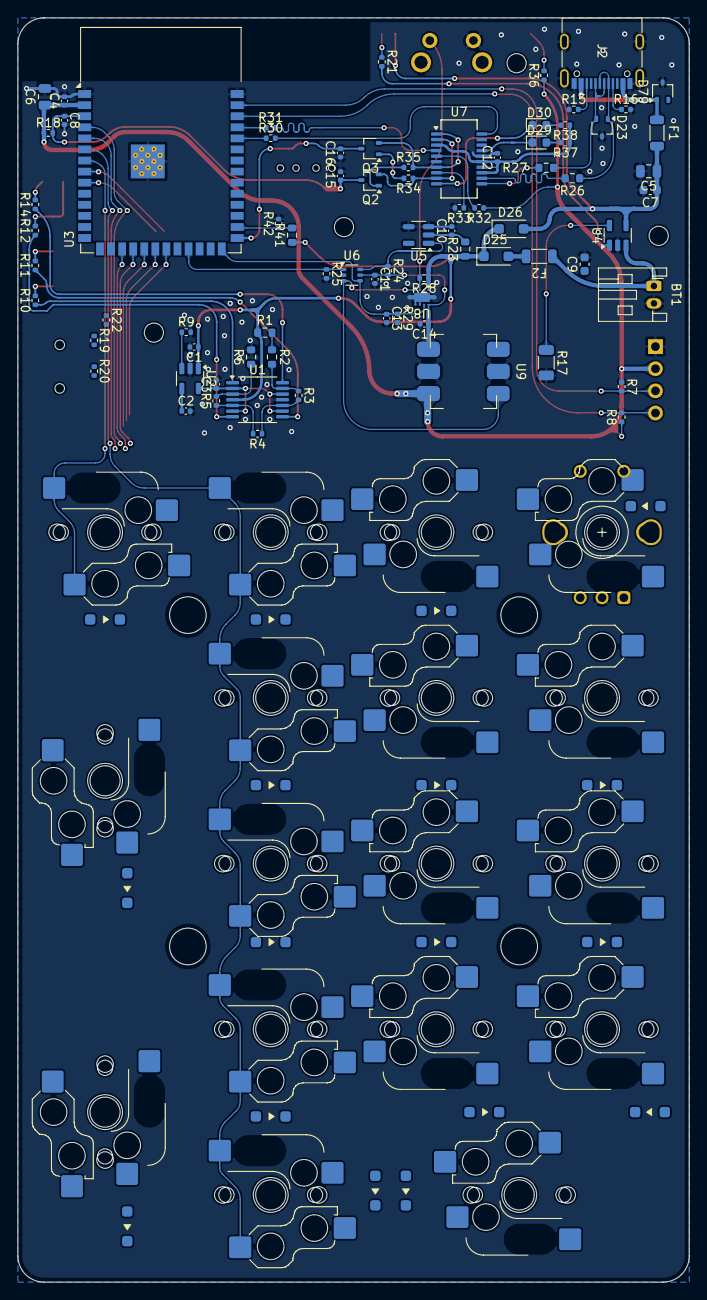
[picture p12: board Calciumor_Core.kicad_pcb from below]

Board: 2 copper layers, 77.0 x 145.0 mm, 127 parts (93 on the bottom side), 90 nets.

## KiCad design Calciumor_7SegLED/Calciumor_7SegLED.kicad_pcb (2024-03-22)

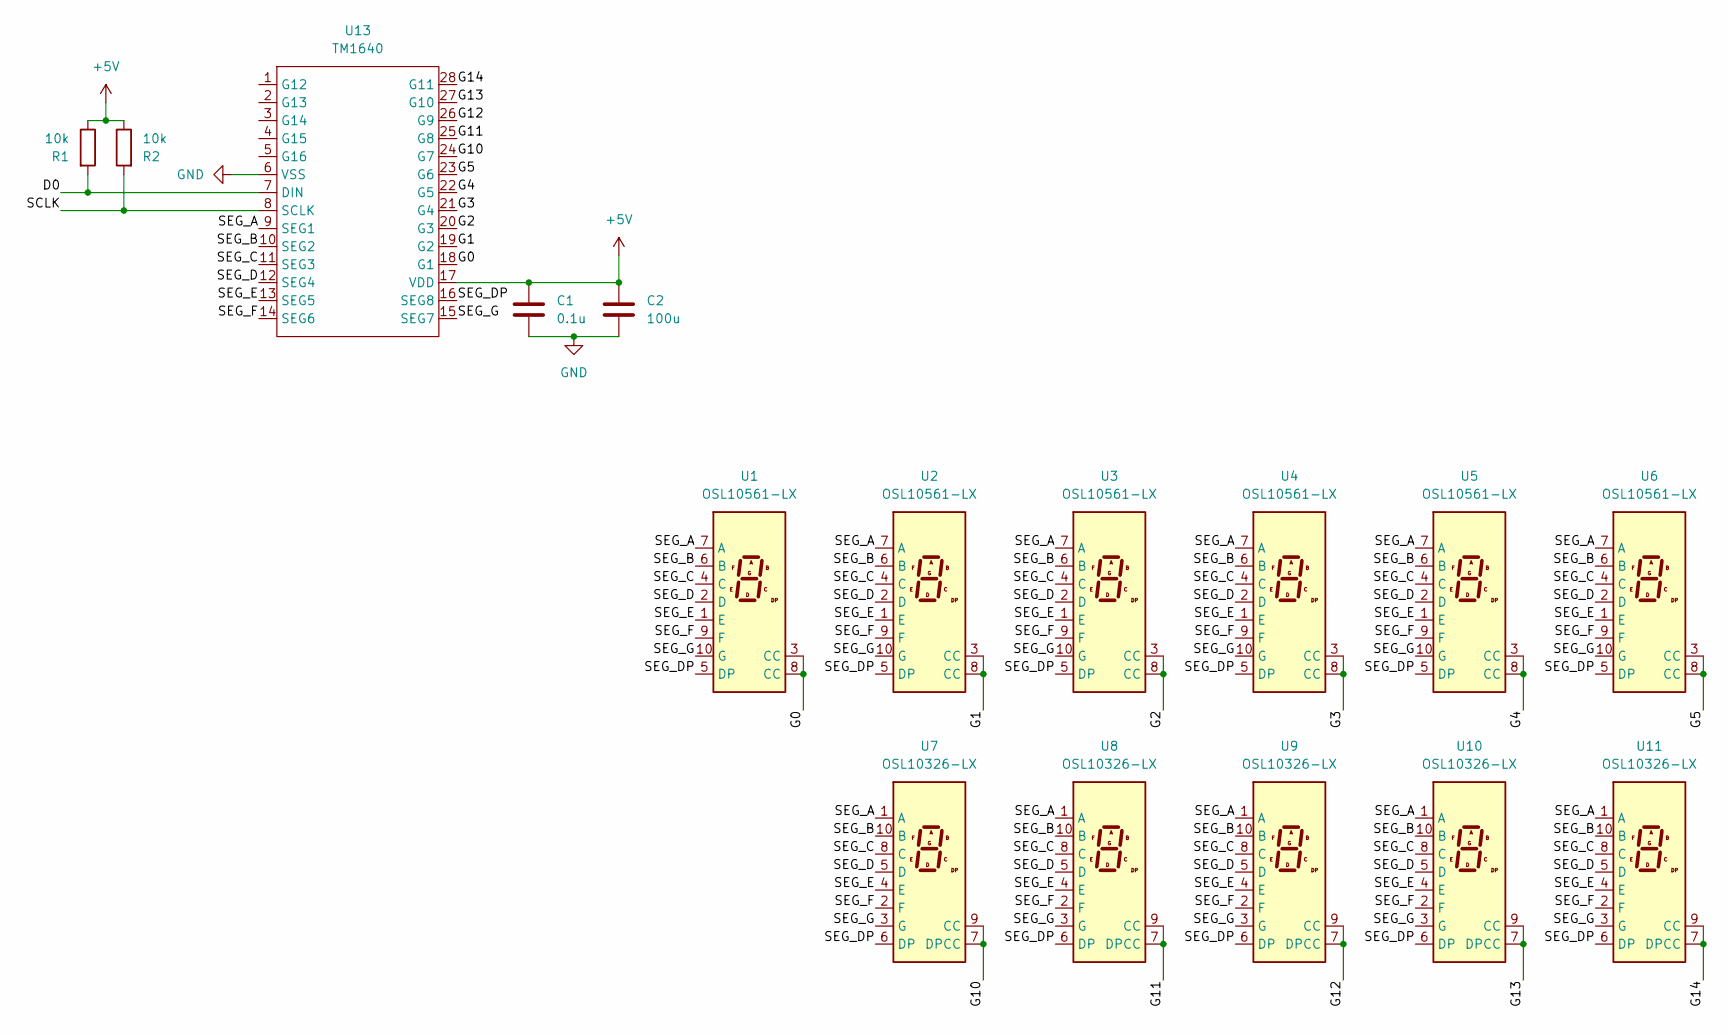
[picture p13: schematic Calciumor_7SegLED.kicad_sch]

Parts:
C1: 0.1u; C_0603_1608Metric_Pad1.08x0.95mm_HandSolder
C2: 100u; C_0603_1608Metric_Pad1.08x0.95mm_HandSolder
R1, R2: 10k; R_0603_1608Metric_Pad0.98x0.95mm_HandSolder
U1, U2, U3, U4, U5, U6: OSL10561-LX
U7, U8, U9, U10, U11: OSL10326-LX
U13: TM1640

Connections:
+5V: C1.1, C2.1, R1.1, R2.1, U13.17 (VDD); also elsewhere on the board
/D0: R1.2, U13.7 (DIN)
/G0: U1.3 (CC), U1.8 (CC), U13.18 (G1)
/G1: U2.3 (CC), U2.8 (CC), U13.19 (G2)
/G2: U3.3 (CC), U3.8 (CC), U13.20 (G3)
/G3: U4.3 (CC), U4.8 (CC), U13.21 (G4)
/G4: U5.3 (CC), U5.8 (CC), U13.22 (G5)
/G5: U6.3 (CC), U6.8 (CC), U13.23 (G6)
/G10: U7.7 (DPCC), U7.9 (CC), U13.24 (G7)
/G11: U8.7 (DPCC), U8.9 (CC), U13.25 (G8)
/G12: U9.7 (DPCC), U9.9 (CC), U13.26 (G9)
/G13: U10.7 (DPCC), U10.9 (CC), U13.27 (G10)
/G14: U11.7 (DPCC), U11.9 (CC), U13.28 (G11)
/SCLK: R2.2, U13.8 (SCLK)
/SEG_A: U1.7 (A), U2.7 (A), U3.7 (A), U4.7 (A), U5.7 (A), U6.7 (A), U7.1 (A), U8.1 (A), U9.1 (A), U10.1 (A), U11.1 (A), U13.9 (SEG1)
/SEG_B: U1.6 (B), U2.6 (B), U3.6 (B), U4.6 (B), U5.6 (B), U6.6 (B), U7.10 (B), U8.10 (B), U9.10 (B), U10.10 (B), U11.10 (B), U13.10 (SEG2)
/SEG_C: U1.4 (C), U2.4 (C), U3.4 (C), U4.4 (C), U5.4 (C), U6.4 (C), U7.8 (C), U8.8 (C), U9.8 (C), U10.8 (C), U11.8 (C), U13.11 (SEG3)
/SEG_D: U1.2 (D), U2.2 (D), U3.2 (D), U4.2 (D), U5.2 (D), U6.2 (D), U7.5 (D), U8.5 (D), U9.5 (D), U10.5 (D), U11.5 (D), U13.12 (SEG4)
/SEG_DP: U1.5 (DP), U2.5 (DP), U3.5 (DP), U4.5 (DP), U5.5 (DP), U6.5 (DP), U7.6 (DP), U8.6 (DP), U9.6 (DP), U10.6 (DP), U11.6 (DP), U13.16 (SEG8)
/SEG_E: U1.1 (E), U2.1 (E), U3.1 (E), U4.1 (E), U5.1 (E), U6.1 (E), U7.4 (E), U8.4 (E), U9.4 (E), U10.4 (E), U11.4 (E), U13.13 (SEG5)
/SEG_F: U1.9 (F), U2.9 (F), U3.9 (F), U4.9 (F), U5.9 (F), U6.9 (F), U7.2 (F), U8.2 (F), U9.2 (F), U10.2 (F), U11.2 (F), U13.14 (SEG6)
/SEG_G: U1.10 (G), U2.10 (G), U3.10 (G), U4.10 (G), U5.10 (G), U6.10 (G), U7.3 (G), U8.3 (G), U9.3 (G), U10.3 (G), U11.3 (G), U13.15 (SEG7)
GND: C1.2, C2.2, U13.6 (VSS); also elsewhere on the board

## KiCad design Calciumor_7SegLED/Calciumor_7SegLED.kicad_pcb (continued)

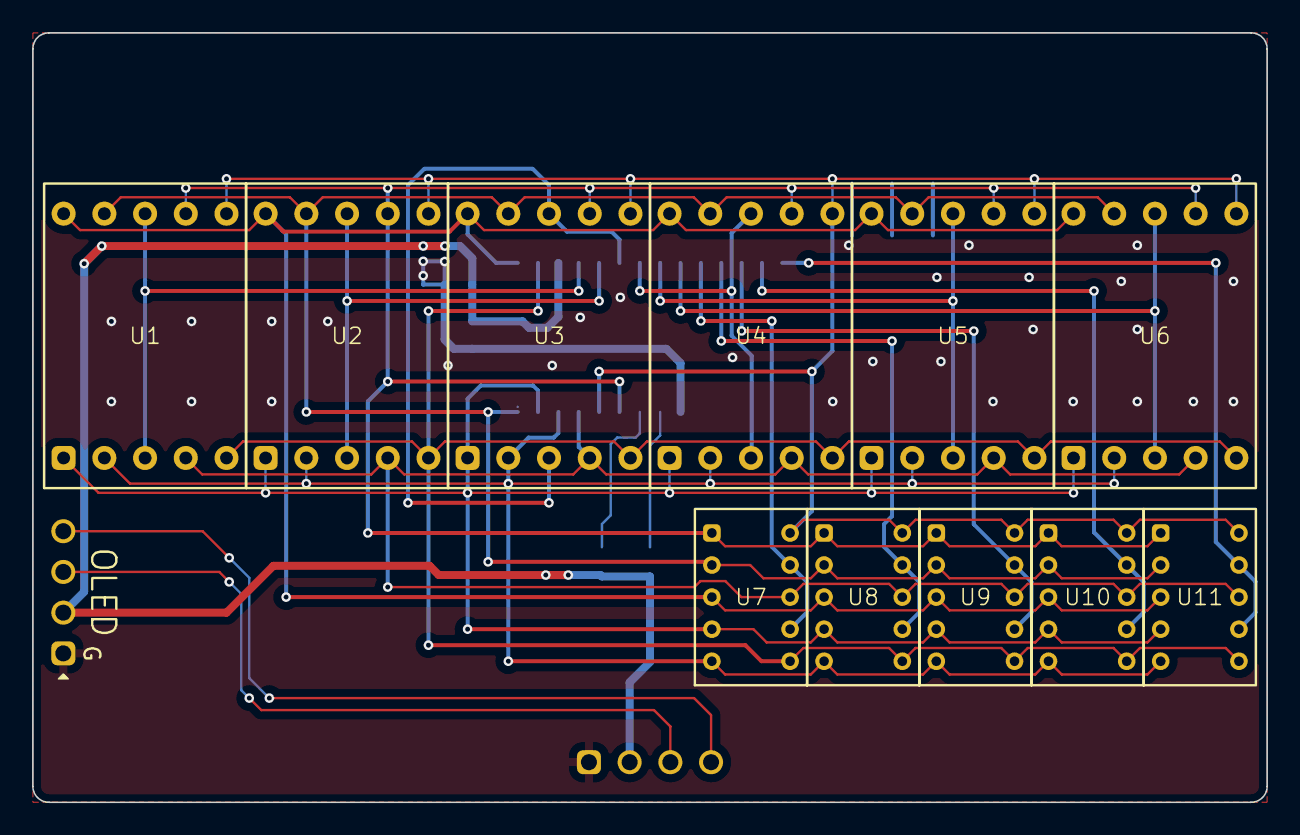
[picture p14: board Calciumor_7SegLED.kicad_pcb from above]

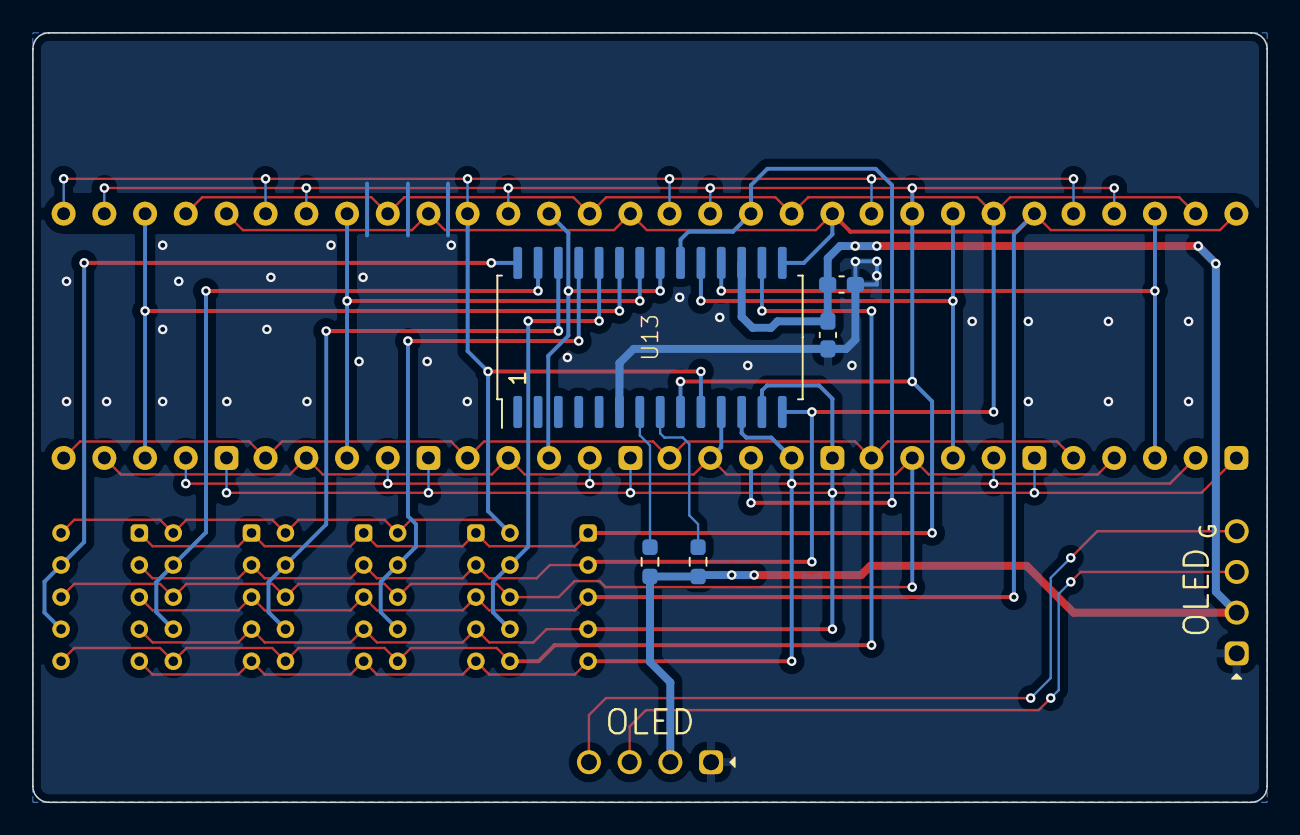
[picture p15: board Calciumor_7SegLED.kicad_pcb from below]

Board: 2 copper layers, 77.0 x 48.0 mm, 18 parts (6 on the bottom side), 25 nets.

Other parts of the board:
J1: OLED; I2C
J2: OLED

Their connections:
+5V: J1.3, J2.3; also elsewhere on the board
/SCL: J1.2, J2.2
/SDA: J1.1, J2.1
GND: J1.4, J2.4; also elsewhere on the board

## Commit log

2024-03-23 Changed to socket switch type
    [Calciumor_Core.kicad_pcb, Calciumor_Core.kicad_sch]
2024-03-26 Adjust Patterns and Pastes
    [Calciumor_Core.kicad_sch]
2024-03-30 Fixed 2V5 Power supply
    [Calciumor_Core.kicad_sch, Calciumor_SwitchCover.kicad_pcb, Calciumor_SwitchCover.kicad_sch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]
2024-04-11 add 5V power source
    [Calciumor_Core.kicad_sch, bom.csv, designators.csv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]
2024-04-25 Changed to native USB
    [Calciumor_Core-Edge_Cuts.dxf, Calciumor_Core-F_Fab.dxf, Calciumor_Core.kicad_sch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]
2024-05-08 Under cover completed
    [Calciumor_SwitchCover-Edge_Cuts.dxf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]
